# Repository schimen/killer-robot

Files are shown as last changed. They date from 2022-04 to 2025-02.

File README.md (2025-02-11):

# Killer robot

This repository contains all code and circuit for the robot **Rupert**, competing in [RoboWars](https://omegav.no/robotkrig) at [Omega Verksted](https://omegav.no/).

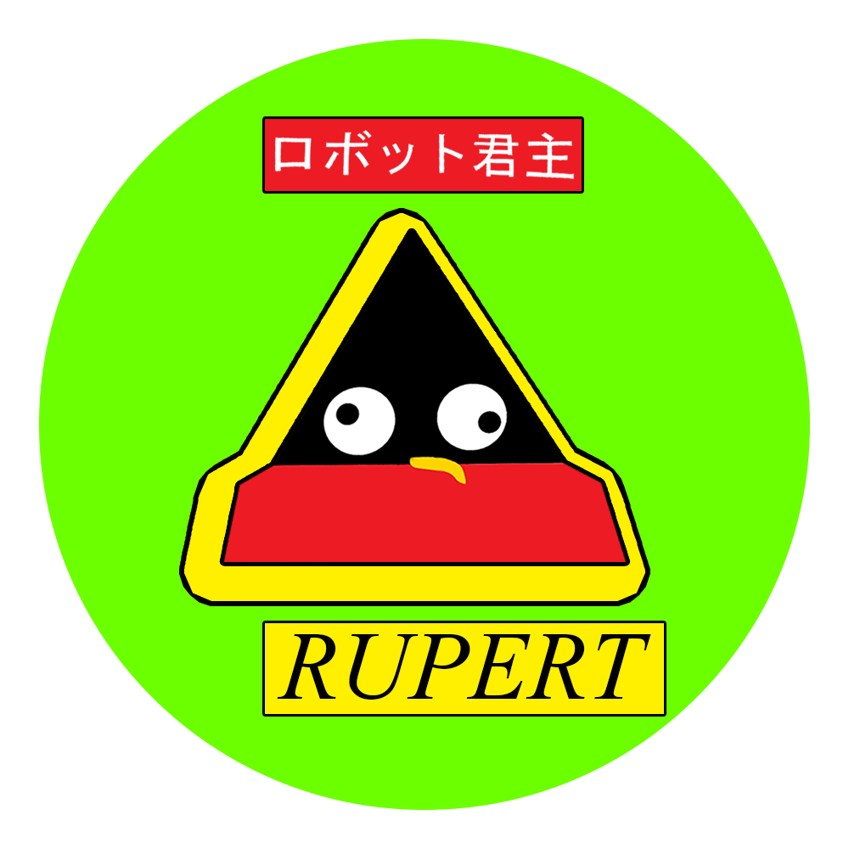
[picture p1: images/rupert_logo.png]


More information about Rupert and his history can be found in [history.md](./history.md).

## Projects

This repository consists of differenct projects that have different tasks in controlling the robot.
The different projects are:
- [Robot brain](./firmware/rupert-brain/): Firmware running on Rupert, receives commands and controls motors.
- [Robot pcb](./robot-pcb/): Printed circuit board supposed to control the robot. The robot brain runs on this hardware.
- [Robot control center](./control-center/): Python GUI program that controls the robot via commands.
- [Transmitter](./firmware/transmitter): Firmware for command transmitter, communicating with the control center via USB and the robot via radio.
This transmitter is deprecated, all communication with Rupert uses BLE via the "Robot control center".

## Zephyr guide

The firmware for Rupert is mainly developed in [Zephyr RTOS](https://www.zephyrproject.org/) and the SDK for Zephyr must be installed to build and upload firmware to the robot and the transmitter.
Zephyr is well documented and the latest documentation can be found [here](https://docs.zephyrproject.org/latest/index.html).

To install and get started with Zephyr, please follow [this guide](https://docs.zephyrproject.org/latest/develop/getting_started/index.html).
To install Zephyr in this project, make sure west and other dependencies from the guide is installed, and run `west update` from this repositories root folder. This will download Zephyr and relevant modules.
After installing and becoming familiar with the framework, you can install dependencies used by our hardware:
- Install ESP32 dependencies with `west espressif install`. Alternatively, follow [this guide](https://www.zephyrproject.org/zephyr-rtos-on-esp32/).

The Rupert firmware can now for example be built by the command `west build -b rupert_pcb firmware/rupert-brain` and then flashed with the command `west flash`.

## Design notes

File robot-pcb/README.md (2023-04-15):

# Robot PCB

This is the PCB that controls Rupert.
It consists of a ESP32 microcontroller that communicates over bluetooth.
Motors are controlled via motor-driver and via pwm outputs.

Schematic:

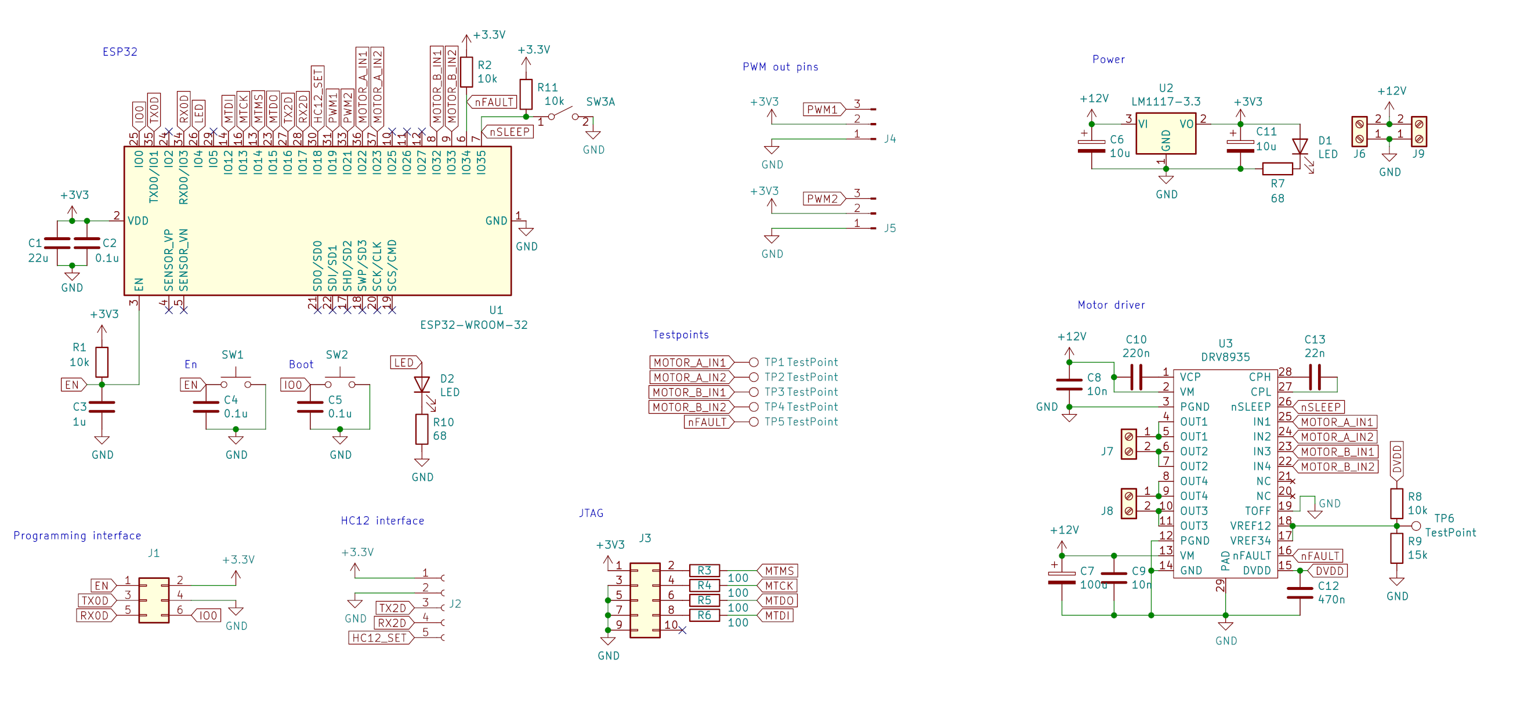
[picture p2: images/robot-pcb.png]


PCB 3d render:

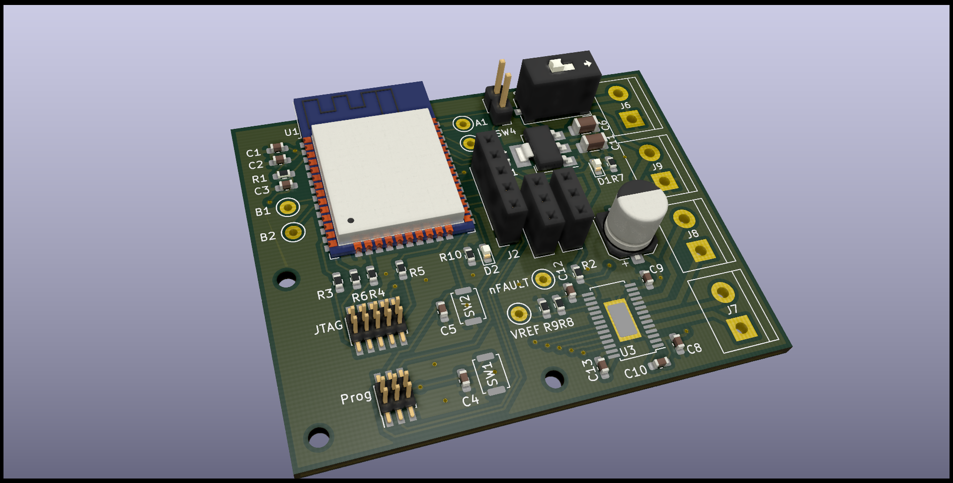
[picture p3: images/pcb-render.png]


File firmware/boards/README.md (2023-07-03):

# Rupert PCB zephyr configuration

This folder contains configuration describing the hardware running on Rupert. It describes the PCB and the expected connections to it. This board should be used when building and flashing code to Rupert.

An ESP32 microcontroller is the brain of the Rupert PCB and this folder therefore mostly uses the default ESP32 configuration for Zephyr.

See [the robot pcb folder](../../robot-pcb/) for details about the pcb.

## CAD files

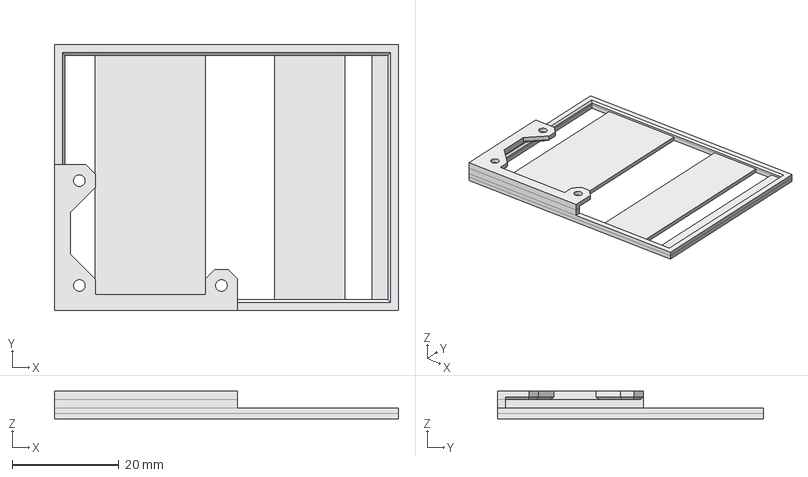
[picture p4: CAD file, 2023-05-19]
3d models/pcb-holder/robot_pcb_holder.FCStd
64.6 x 49.9 x 5.20 mm

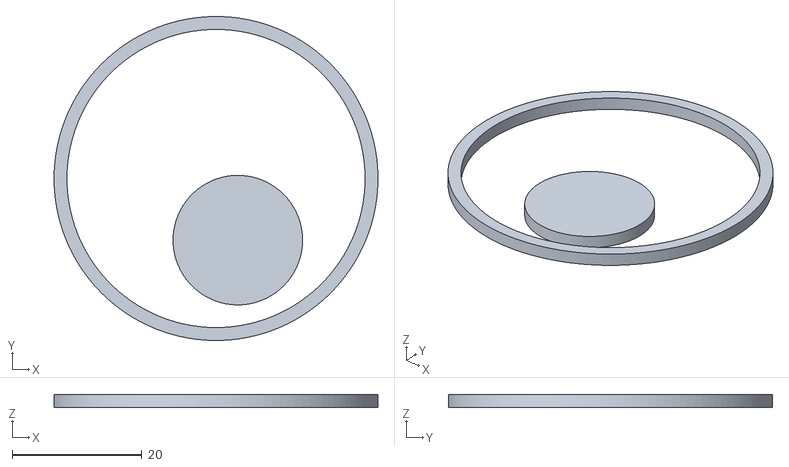
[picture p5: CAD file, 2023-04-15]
3d models/rupert-eyes/eye_black.stl
50.0 x 50.0 x 2.00

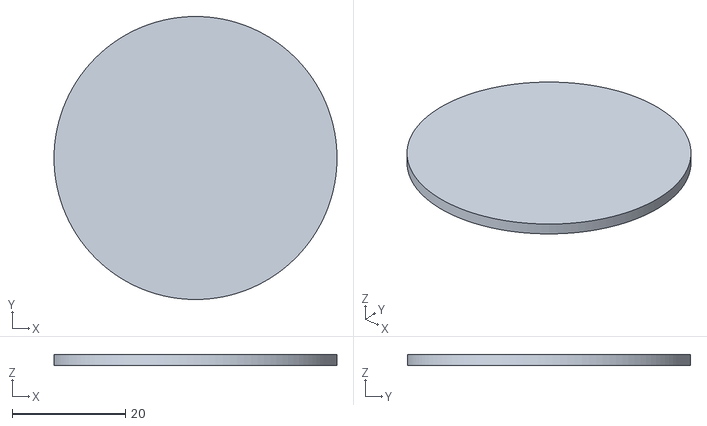
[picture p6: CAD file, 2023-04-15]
3d models/rupert-eyes/eye_hvite.stl
50.0 x 50.0 x 2.00

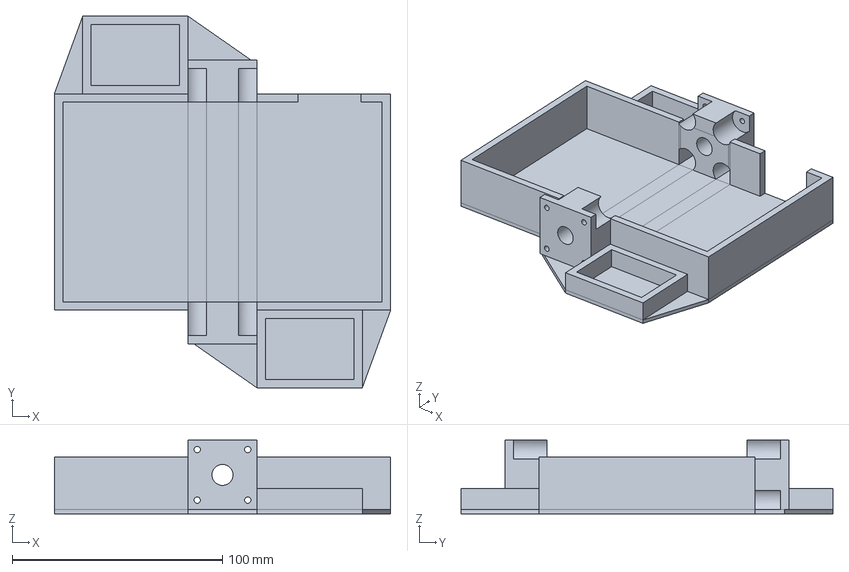
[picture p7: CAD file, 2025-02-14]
3d models/spinner-model/chassis-v3.FCStd
160.0 x 177.0 x 35.0 mm

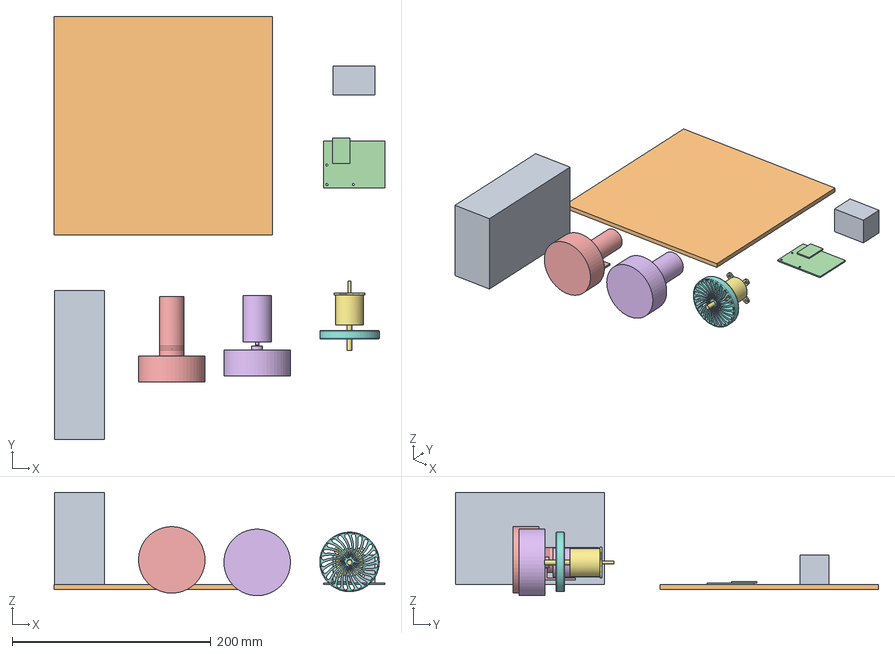
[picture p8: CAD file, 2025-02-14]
3d models/spinner-model/common-components.FCStd
333.1 x 426.0 x 104.0 mm
Battery V1
plate
PCB plate
ESP32 module
DC Motor 1
BL Motor car 1
BL Motor drone 1
Drone wheel 1

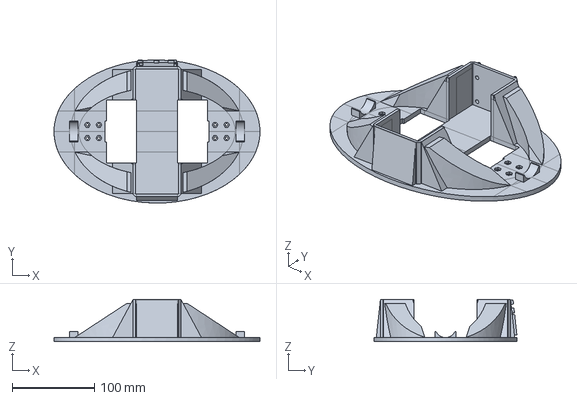
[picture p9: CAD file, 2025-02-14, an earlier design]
3d models/spinner-model/chassis-v1.FCStd
250.0 x 173.7 x 51.5 mm

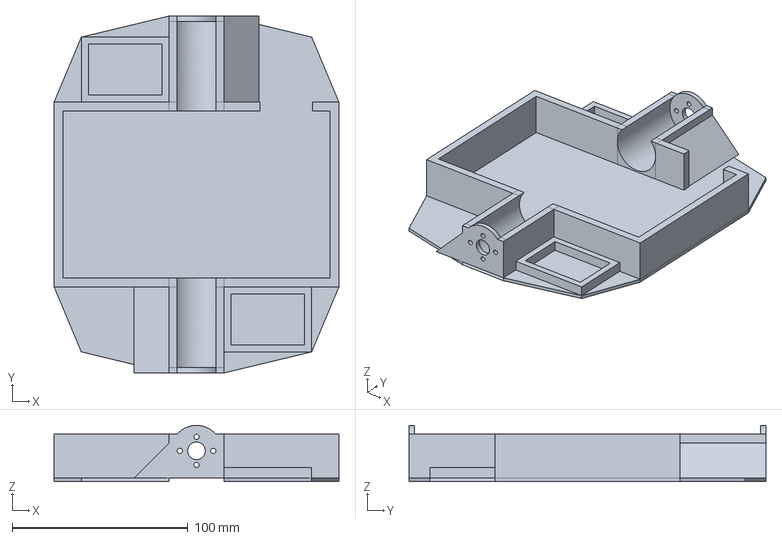
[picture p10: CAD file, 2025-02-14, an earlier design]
3d models/spinner-model/chassis-v2.FCStd
162.0 x 203.0 x 32.0 mm

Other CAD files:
3d models/pcb-holder/robot_pcb_holder.stl

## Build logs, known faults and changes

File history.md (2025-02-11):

# Rupert history

Rupert regularly undergoes changes, and so far there have been three versions of Rupert. The first Rupert competing in Robowars autumn 2021, Señor Rupert jr and Captain Rupert competing in robowars autumn 2022 and spring 2023 and our newest Rupert in autumn 2023.

Results can be seen at [confluence](https://confluence.omegav.no/display/OV/Tidligere+resultater).

### Rupert

*Autumn 2021* - ([Branch](https://github.com/schimen/killer-robot/tree/rupert-h2021))

The first Rupert to compete. Rupert did not have any efficient weapons, but he had a very durable shell which protected him from dangerous attacks. 
Rupert fought well but with a lack of attack he could not compete with the top. Rupert came in 3rd place.

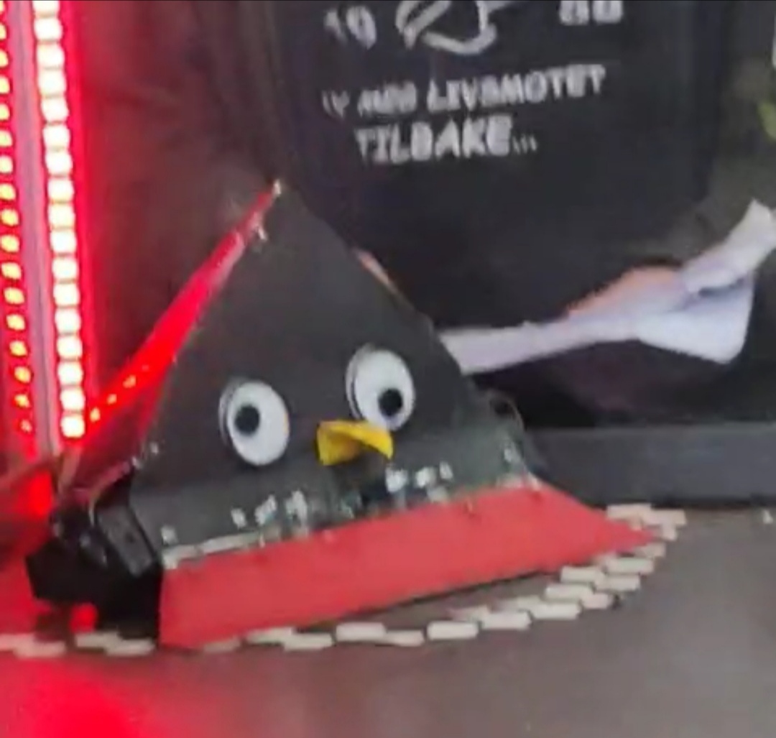
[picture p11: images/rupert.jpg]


### Señor Rupert jr

*Autumn 2022* - ([Branch](https://github.com/schimen/killer-robot/tree/rupert-h2022))

The next Rupert to compete had a 600g steel cylinder with teeth which was spinning at an impressive speed. Now that Rupert was equipped with a weapon, he was able to bite back at the opponents.
Rupert fought more aggressively this time and he did very well, but the electronics could not handle the heat and ended up burning themselves up in the process. Rupert came in 2nd place.

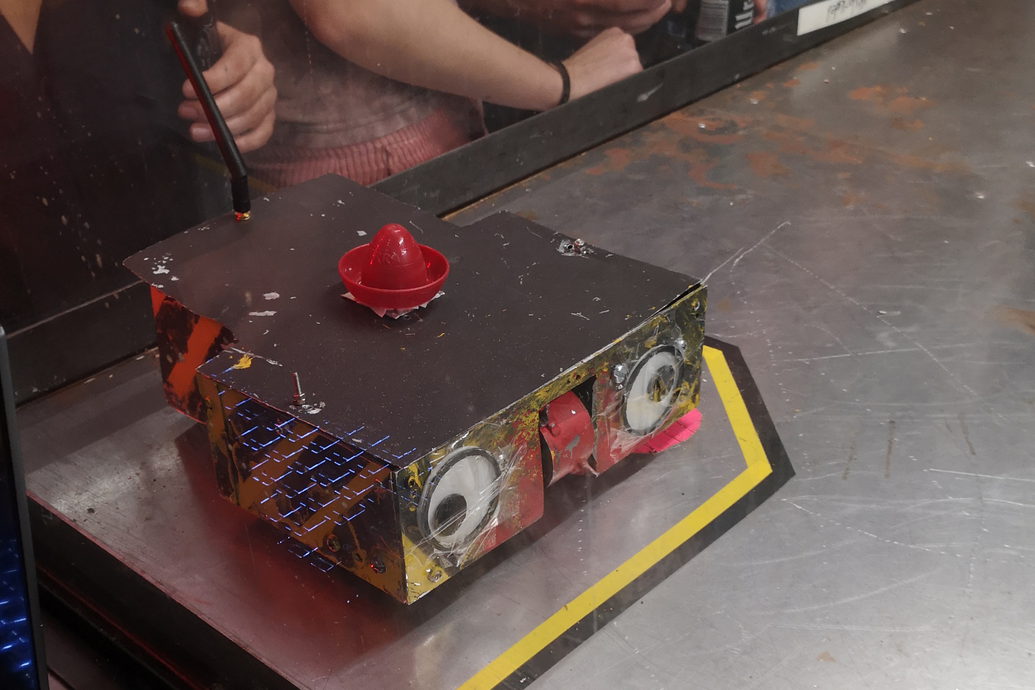
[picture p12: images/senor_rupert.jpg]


### Captain Rupert

*Spring 2023* - ([Branch](https://github.com/schimen/killer-robot/tree/rupert-v2023))

Rupert was again equipped with the teeth, and armed with more experience.
He fought like a pirate, with everything he got, but in the final fight his weapon was destroyed and the final battle was lost. He still came in a shared 1st place.

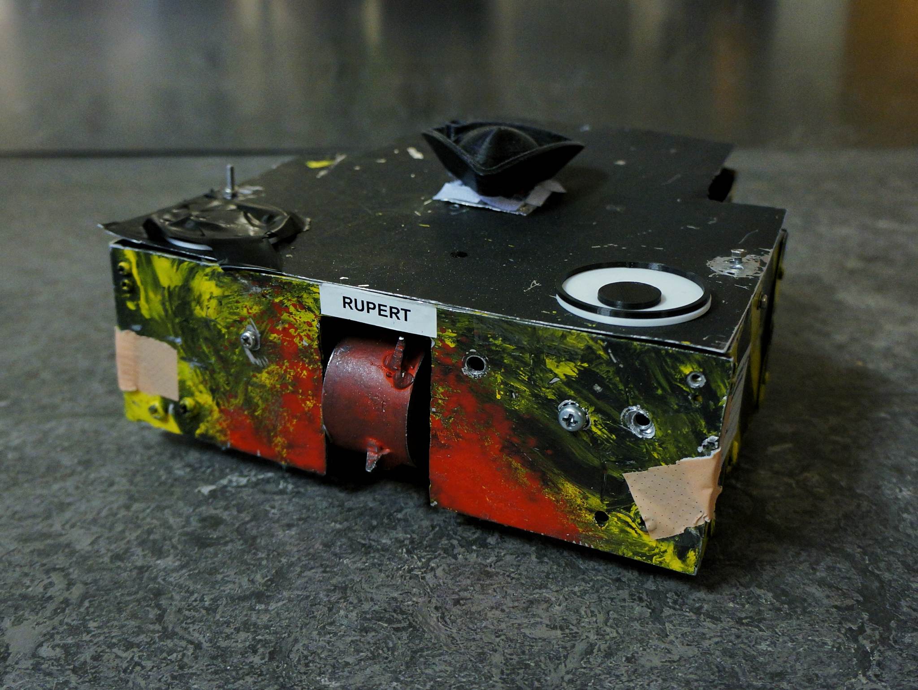
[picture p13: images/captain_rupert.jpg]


### Rupert

*Autumn 2023* - ([Branch](https://github.com/schimen/killer-robot/tree/rupert-h2023))

This time Rupert came out of his shell with a new strategy. He brought his padlock and threw it around at the opponents.
Rupert survived surprisingly long in the arena but was sadly obliterated immediately when he met an opponent with a fast spinning weapon. Rupert came in 3rd place.

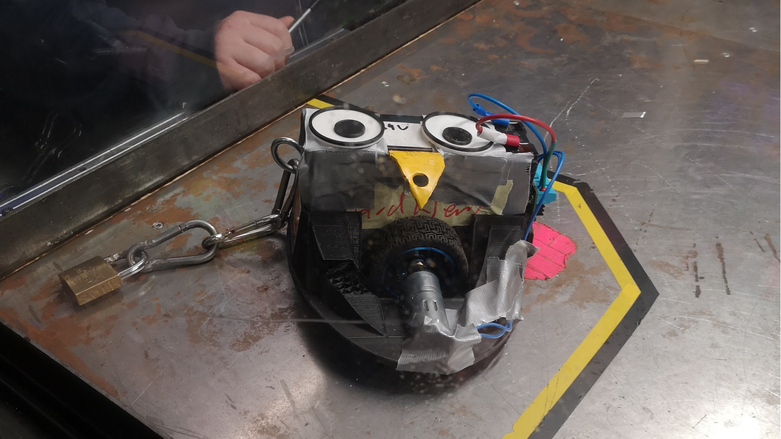
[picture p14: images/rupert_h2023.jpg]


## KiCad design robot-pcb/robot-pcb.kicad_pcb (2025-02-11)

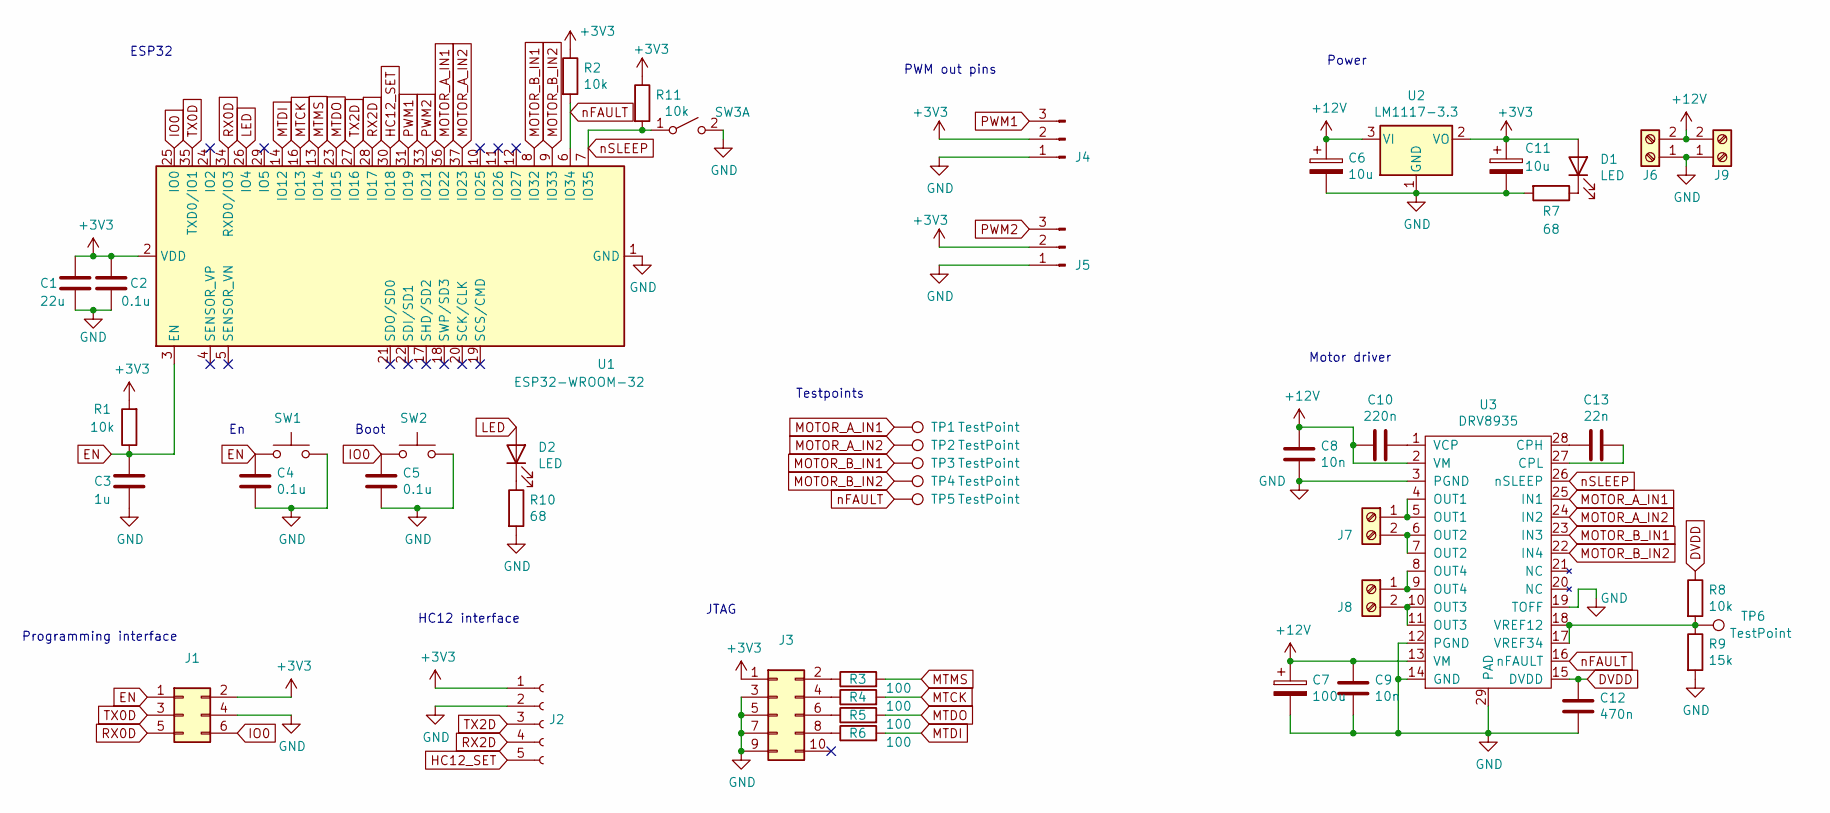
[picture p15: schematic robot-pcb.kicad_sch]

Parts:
C1: 22u; C_0603_1608Metric_Pad1.08x0.95mm_HandSolder
C2, C4, C5: 0.1u; C_0603_1608Metric_Pad1.08x0.95mm_HandSolder
C3: 1u; C_0603_1608Metric_Pad1.08x0.95mm_HandSolder
C6, C11: 10u; C_1206_3216Metric_Pad1.33x1.80mm_HandSolder
C7: 100u; CP_Elec_6.3x7.7
C8, C9: 10n; C_0603_1608Metric_Pad1.08x0.95mm_HandSolder
C10: 220n; C_0603_1608Metric_Pad1.08x0.95mm_HandSolder
C12: 470n; C_0603_1608Metric_Pad1.08x0.95mm_HandSolder
C13: 22n; C_0603_1608Metric_Pad1.08x0.95mm_HandSolder
D1, D2: LED; LED_0603_1608Metric_Pad1.05x0.95mm_HandSolder
J1: Conn_02x03_Odd_Even; PinHeader_2x03_P1.27mm_Vertical_SMD
J2: Conn_01x05_Female; PinSocket_1x05_P2.54mm_Vertical
J3: Conn_02x05_Odd_Even; PinHeader_2x05_P1.27mm_Vertical_SMD
J4, J5: Conn_01x03_Male; PinSocket_1x03_P2.54mm_Vertical
J6, J7, J8, J9: Screw_Terminal_01x02; TerminalBlock_bornier-2_P5.08mm
R1, R2, R8, R11: 10k; R_0603_1608Metric_Pad0.98x0.95mm_HandSolder
R3, R4, R5, R6: 100; R_0603_1608Metric_Pad0.98x0.95mm_HandSolder
R7, R10: 68; R_0603_1608Metric_Pad0.98x0.95mm_HandSolder
R9: 15k; R_0603_1608Metric_Pad0.98x0.95mm_HandSolder
SW1, SW2: SW_Push; wurth_tactile_sw
SW3: SW_DPST_x2; PinHeader_1x02_P2.54mm_Vertical
TP1, TP2, TP3, TP4, TP5, TP6: TestPoint; TestPoint_Keystone_5000-5004_Miniature
U1: ESP32-WROOM-32
U2: LM1117-3.3; SOT-223
U3: DRV8935; HTSSOP-28-1EP_4.4x9.7mm_P0.65mm_EP2.85x5.4mm

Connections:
+3V3: C1.1, C2.1, C11.1, D1.2 (A), J1.2, J2.1, J3.1, J4.2, J5.2, R1.2, R2.1, R11.1, U1.2 (VDD), U2.2 (VO), U2.4
+12V: C6.1, C7.1, C8.1, C9.1, C10.2, J6.2, J9.2, U2.3 (VI), U3.2 (VM), U3.13 (VM)
DVDD: C12.1, R8.1, U3.15 (DVDD)
EN: C3.1, C4.1, J1.1, R1.1, SW1.2, U1.3 (EN)
GND: C1.2, C2.2, C3.2, C4.2, C5.2, C6.2, C7.2, C8.2, C9.2, C11.2, C12.2, J1.4, J2.2, J3.3, J3.5, J3.7, J3.9, J4.1, J5.1, J6.1, J9.1, R7.2, R9.2, R10.2, SW1.1, SW2.2, SW3.2 (B), U1.1 (GND), U1.15 (GND), U1.38 (GND), U1.39 (GND), U2.1 (GND), U3.3 (PGND), U3.12 (PGND), U3.14 (GND), U3.19 (TOFF), U3.29 (PAD)
HC12_SET: J2.5, U1.30 (IO18)
IO0: C5.1, J1.6, SW2.1, U1.25 (IO0)
LED: D2.2 (A), U1.26 (IO4)
MOTOR_A_IN1: TP1.1, U1.36 (IO22), U3.25 (IN1)
MOTOR_A_IN2: TP2.1, U1.37 (IO23), U3.24 (IN2)
MOTOR_B_IN1: TP3.1, U1.8 (IO32), U3.23 (IN3)
MOTOR_B_IN2: TP4.1, U1.9 (IO33), U3.22 (IN4)
MTCK: R4.2, U1.16 (IO13)
MTDI: R6.2, U1.14 (IO12)
MTDO: R5.2, U1.23 (IO15)
MTMS: R3.2, U1.13 (IO14)
unnamed: C10.1, U3.1 (VCP)
unnamed: C13.1, U3.27 (CPL)
unnamed: C13.2, U3.28 (CPH)
unnamed: D1.1 (K), R7.1
unnamed: D2.1 (K), R10.1
unnamed: J3.2, R3.1
unnamed: J3.4, R4.1
unnamed: J3.6, R5.1
unnamed: J3.8, R6.1
unnamed: J7.1, U3.4 (OUT1), U3.5 (OUT1)
unnamed: J7.2, U3.6 (OUT2), U3.7 (OUT2)
unnamed: J8.1, U3.8 (OUT4), U3.9 (OUT4)
unnamed: J8.2, U3.10 (OUT3), U3.11 (OUT3)
unnamed: R8.2, R9.1, TP6.1, U3.17 (VREF34), U3.18 (VREF12)
PWM1: J4.3, U1.31 (IO19)
PWM2: J5.3, U1.33 (IO21)
RX0D: J1.5, U1.34 (RXD0/IO3)
RX2D: J2.4, U1.28 (IO17)
TX0D: J1.3, U1.35 (TXD0/IO1)
TX2D: J2.3, U1.27 (IO16)
nFAULT: R2.2, TP5.1, U1.6 (IO34), U3.16 (nFAULT)
nSLEEP: R11.2, SW3.1 (A), U1.7 (IO35), U3.26 (nSLEEP)

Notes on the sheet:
PWM out pins
ESP32
Motor driver
JTAG
HC12 interface
Power
Testpoints
Boot
Programming interface

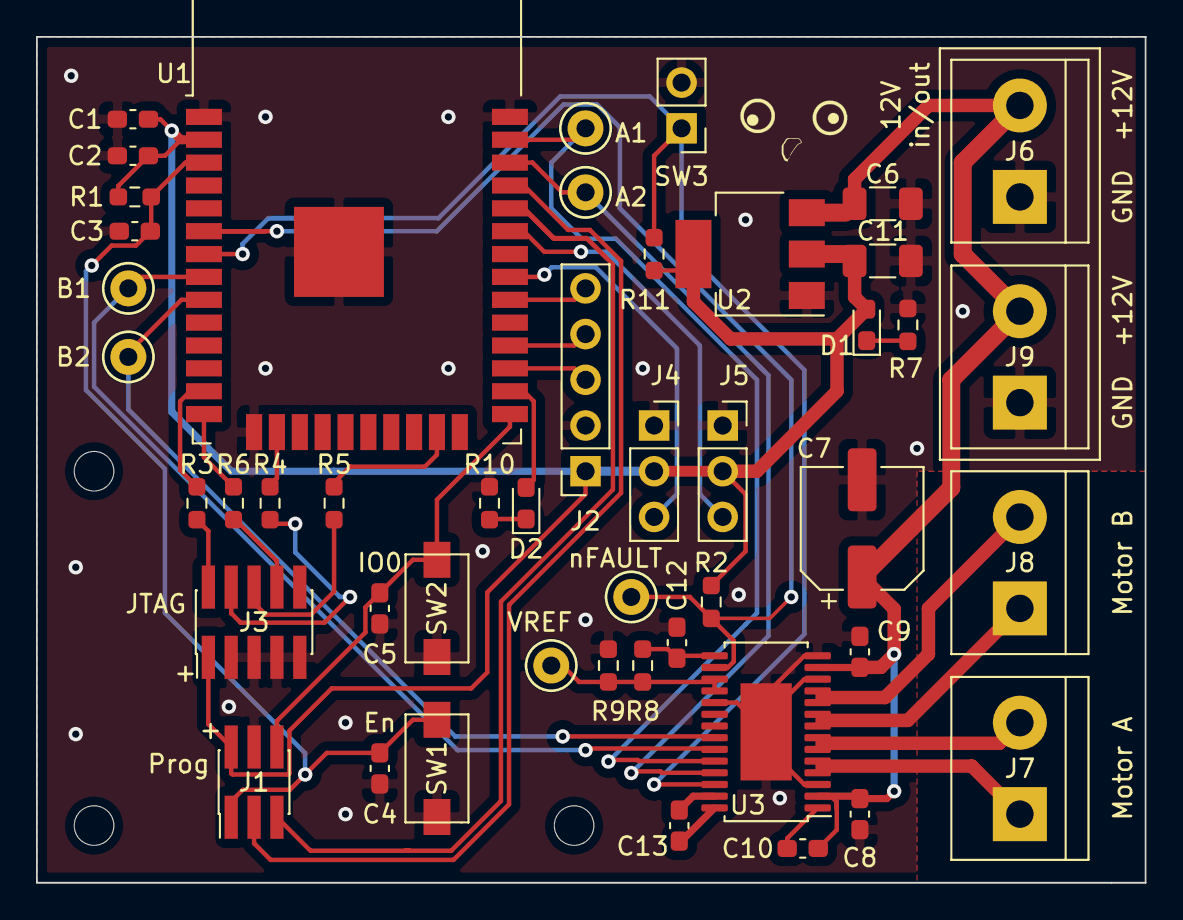
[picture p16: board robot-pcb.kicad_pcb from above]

Board: 2 copper layers, 61.6 x 47.0 mm, 47 parts (0 on the bottom side), 38 nets.

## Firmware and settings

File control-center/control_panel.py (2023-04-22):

"""
Control panel for killer robot
Made by Simen
"""
from os import system
from sys import platform
import threading
import tkinter as tk
from tkinter import ttk
import atexit
from time import sleep

from communication import \
    list_comports, Communication

# global sets for keeping an eye in the keys (little ugly solution, i know ;( )
pressed_keys = set()

# Global object for sending messages
comm = Communication()

class windows(tk.Tk):
    def __init__(self, *args, **kwargs):
        tk.Tk.__init__(self, *args, **kwargs)
        # Adding a title to the window
        self.wm_title("Control panel")
 
        # creating a frame and assigning it to container
        container = tk.Frame(self)
        # specifying the region where the frame is packed in root
        container.pack(side="top", fill="both", expand=True)
 
        # configuring the location of the container using grid
        container.grid_rowconfigure(0, weight=1)
        container.grid_columnconfigure(0, weight=1)

        self.frames = {}
        for i, F in enumerate((ControlOptions, Controls, DeviceOptions, BluetoothOptions)):
            frame = F(container, self)
            frame.grid(row=i, column=0)
            self.frames[frame.name] = frame

class Controls(tk.Frame):
    def __init__(self, parent, _):
        self.name = "Controls"
        tk.Frame.__init__(self, parent) 
        label = tk.Label(self, text="Controls")

        # Buttons that can be used controlling the robot.
        # These buttons does not do anything, but indicates which keys are pressed.
        Controls.buttons = dict()
        label.grid(row=0,column=1)
        control_buttons = { 'w': (1, 2)
                          , 'a': (2, 1)
                          , 's': (2, 2)
                          , 'd': (2, 3)
                          , 'shift': (3, 0)
                          , 'alt':   (3, 1)
                          , 'space': (3, 2)
                          }
        for key, (i, j) in control_buttons.items():
            new_button = tk.Button(
                self, 
                text = key,
            )
            new_button.grid(row=i, column=j)
            Controls.buttons[key] = new_button


class ControlOptions(tk.Frame):
    def __init__(self, parent, _):
        self.name = "ControlOptions"
        tk.Frame.__init__(self, parent) 
        label = tk.Label(self, text="Control Options")
        label.grid(row=0, column=1)

        # create entries for the options
        self.weapon_entry = create_option_entry(
            self, 'Weapon speed', (1, 0), self.weapon_speed
        )
        self.forward_entry = create_option_entry(
            self, 'Forward speed', (2, 0), self.forward_speed
        )
        self.backward_entry = create_option_entry(
            self, 'Backward speed', (3, 0), self.backward_speed
        )
        self.turnrate_entry = create_option_entry(
            self, 'Turning rate', (4, 0), self.turn_fraction
        )
        # setting alternate variables
        self.set_shift_values = create_option_check(
            self, (4, 0), 0, 
            text = 'Set shift values', onvalue = 1, offvalue = 0,
            command = self.set_shift_entries
        )
        # update the variables
        update_button = tk.Button(
            self, 
            text = 'Update values', command = self.update_values
        )
        update_button.grid(row=5, column=1)

    def update_values(self):
        # unfocus entries
        control_panel.focus()

        # set weapon speed
        weapon_var = get_speed(self.weapon_entry)
        if weapon_var is None:
            print('Weapon entry needs number')
            return

        # set forward speed
        forward_var = get_speed(self.forward_entry)
        if forward_var is None:
            print('Forward entry needs number')
            return
        
        # set bacwkard speed
        backward_var = get_speed(self.backward_entry)
        if backward_var is None:
            print('Backward entry needs number')
            return

        # set turning rate
        turnrate_str = self.turnrate_entry.get()
        # this will cause ValueError if `turnrate_str` can not be translated to a float
        try:
            min_turnrate = 0.1; max_turnrate = 2
            limited_value = limit_value(min_turnrate, max_turnrate, float(turnrate_str))
            turn_var = limited_value
        except ValueError:
            print('Turn fraction needs float')
            return

        if self.set_shift_values.get() > 0: # setting alternate speed
            print("Setting alternate speed")
            ControlOptions.weapon_speed_alt = weapon_var
            ControlOptions.forward_speed_alt = forward_var
            ControlOptions.backward_speed_alt = backward_var
            ControlOptions.turn_fraction_alt = turn_var
        else:                               # setting normal speed
            print("Setting normal speed")
            ControlOptions.weapon_speed = weapon_var
            ControlOptions.forward_speed = forward_var 
            ControlOptions.backward_speed = backward_var
            ControlOptions.turn_fraction = turn_var

    def set_shift_entries(self):
        # Clear all entries
        self.weapon_entry.delete(0, 4)
        self.forward_entry.delete(0, 4)
        self.backward_entry.delete(0, 4)
        self.turnrate_entry.delete(0, 4)

        if self.set_shift_values.get() > 0:
            self.weapon_entry.insert(0, str(ControlOptions.weapon_speed_alt))
            self.forward_entry.insert(0, str(ControlOptions.forward_speed_alt))
            self.backward_entry.insert(0, str(ControlOptions.backward_speed_alt))
            self.turnrate_entry.insert(0, str(ControlOptions.turn_fraction_alt))

        else:
            self.weapon_entry.insert(0, str(ControlOptions.weapon_speed))
            self.forward_entry.insert(0, str(ControlOptions.forward_speed))
            self.backward_entry.insert(0, str(ControlOptions.backward_speed))
            self.turnrate_entry.insert(0, str(ControlOptions.turn_fraction))

class DeviceOptions(tk.Frame):
    def __init__(self, parent, _):
        self.name = "DeviceOptions"
        tk.Frame.__init__(self, parent)
        label = tk.Label(self, text="Device Options")
        label.grid(row=0, column = 1)
        # Update the serial device list every 5 seconds
        threading.Thread(target=self.update_port_list, args=(5,), daemon=True).start()
        self.interface = comm.serial

        # Settings for transmitter device
        self.port_combo = create_option_combo(
            self, 'Port', (1, 0), []
        )
        self.baud_entry = create_option_entry(
            self, 'Baud rate', (2, 0), 115200)
        self.open_button = tk.Button(
            self, text = 'Open serial', command = self.open_serial
        )
        self.open_button.grid(row=3, column = 1)
        self.pings = []
        self.ping_var = tk.StringVar()
        tk.Label(
            self, textvariable=self.ping_var, 
        ).grid(row=3, column=0)

    def open_serial(self):
        # Close port if it is already open
        if self.interface.ser.is_open:
            comm.remove_interface(self.interface)
            self.interface.ser.close()
            print('Closed serial')
            self.ping_var.set('')
            self.open_button.config(text='Open serial')
            return
        
        # unfocus entries
        control_panel.focus()

        # Open serial
        baudrate = self.baud_entry.get()
        if not baudrate.isdigit():
            print('Baudrate must be an integer')
            return

        if self.interface.open_serial(
            self.port_combo.get(), int(baudrate)
            ):
            comm.add_interface(self.interface, 1, self.send_cb)
            # If the serial opened succesfully, 
            # the button will now close the serial
            self.open_button.config(text=f'Close serial')
            # print all serial communication to terminal
            threading.Thread(target=self.interface.read_serial_thread, daemon=True).start()

    def update_port_list(self, interval):
        while True:
            self.device_list = list_comports()
            self.port_combo['values'] = self.device_list
            sleep(interval)

    def send_cb(self, time):
        # Calculate ping based on last average 10 times
        self.pings.append(time)
        if len(self.pings) > 10:
            self.pings.pop(0)
        ping = sum(self.pings)/len(self.pings)
        # Set ping at control panel
        self.ping_var.set(f'Ping: {str(int(ping*1000)).rjust(3)} ms')

class BluetoothOptions(tk.Frame):
    def __init__(self, parent, _):
        self.name = "BluetoothOptions"
        tk.Frame.__init__(self, parent)
        label = tk.Label(self, text="Bluetooth options")
        label.grid(row=0, column = 1)
        self.pings = []
        self.interface = comm.bluetooth

        # Settings for ble device
        self.device_entry = create_option_entry(
            self, 'BLE device name', (1, 0), 'rupert'
        )
        self.open_button = tk.Button(
            self, text = 'Connect', command = self.bt_connect
        )
        self.open_button.grid(row=3, column = 1)
        self.ping_var = tk.StringVar()
        tk.Label(
            self, textvariable=self.ping_var, 
        ).grid(row=3, column=0)

    def bt_disconnect_cb(self, *_):
        comm.remove_interface(self.interface)
        self.ping_var.set('')
        print('Disconnected')
        try:
            self.open_button.config(text='Connect')
        except tk.TclError:
            print('GUI already closed')
            

    def bt_connect_cb(self):
        comm.add_interface(self.interface, 0, self.send_cb)
        self.open_button.config(text='Disconnect')
        print('Connected')

    def bt_connect(self):
        # Unfocus entries after pressing connect button
        control_panel.focus()

        # Disconnect if already connected
        if self.interface.client:
            if self.interface.client.is_connected:
                print('Try to disconnect')
                threading.Thread(
                    target=self.interface.disconnect,
                ).start()
                return

        name = self.device_entry.get()
        threading.Thread(
            target=self.interface.connect,
            args=(name, self.bt_connect_cb, self.bt_disconnect_cb),
            daemon=True

        ).start()
    
    def send_cb(self, time):
        # Calculate ping based on last average 10 times
        self.pings.append(time)
        if len(self.pings) > 10:
            self.pings.pop(0)
        ping = sum(self.pings)/len(self.pings)
        # Set ping at control panel
        self.ping_var.set(f'Ping: {str(int(ping*1000)).rjust(3)} ms')


# limit the values so they do not exceed max-values
def limit_value(minimum, maximum, value):
    if value <= minimum:
        return minimum   

    elif value >= maximum:
        return maximum

    return value

def get_speed(entry, min_val=-100, max_val=100):
    # set weapon speed
    entry_str = entry.get()
    if entry_str.isdigit():
        return limit_value(min_val, max_val, int(entry_str))
    else:
        return None

def key_press(event):
    """ called when key is pressed """
    pressed_keys.add(event.keycode)
    process_keys()

def key_release(event):
    """ called when key is released """
    pressed_keys.remove(event.keycode)
    process_keys()

def process_keys():
    """ called every time a key  is pressed or released """

    # different key numbers for different platforms (here is only linux and windows)
    if platform == 'linux':
        key_links = { 25: 'w'
                    , 38: 'a'
                    , 39: 's'
                    , 40: 'd'
                    ,  9: 'esc'
                    , 50: 'shift' 
                    , 65: 'space'
                    , 36: 'enter'
                    , 64: 'alt'
                    }
    else : 
        key_links = { 87: 'w'
                    , 65: 'a'
                    , 83: 's'
                    , 68: 'd'
                    , 27: 'esc'
                    , 16: 'shift' 
                    , 32: 'space'
                    , 36: 'enter' # windows value?
                    , 64: 'alt' # windows value?
                    }
    # if there is no change since last time keys were pressed
    if pressed_keys == process_keys.last_pressed_keys:
        return
    process_keys.last_pressed_keys = pressed_keys.copy()
    # filter out uninteresting keys
    relevant_keys = set(filter(lambda x: x in key_links, pressed_keys))
    # get key names from key numbers
    keys = list(map(lambda x: key_links[x], relevant_keys))
    # make buttons on control panel look like they are pressed
    ghostpress_buttons(keys)

    if 'esc' in keys: # unfocus stuff
        control_panel.focus()

    # Calculate motor speeds
    motor_a, motor_b, motor_w = calculate_speed(keys)
    
    # send the message :)
    comm.send_message(motor_a, motor_b, motor_w)

# Static variable for keeping tab on prevous pressed keys
process_keys.last_pressed_keys = set()

def ghostpress_buttons(keys):
    # make the keys look like they are pressed
    for key, button in Controls.buttons.items():
        if key in keys:
            button.config(relief='sunken') # pressed key
        else:
            button.config(relief='raised') # non pressed key

def calculate_speed(keys):
    if 'alt' in keys: # alternate speed
        weapon_speed   = ControlOptions.weapon_speed_alt
        forward_speed  = ControlOptions.forward_speed_alt
        backward_speed = ControlOptions.backward_speed_alt
        turn_fraction  = ControlOptions.turn_fraction_alt
    else:               # normal speed
        weapon_speed   = ControlOptions.weapon_speed
        forward_speed  = ControlOptions.forward_speed
        backward_speed = ControlOptions.backward_speed
        turn_fraction  = ControlOptions.turn_fraction

    motor_a = 0
    motor_b = 0
    motor_w = 0

    if 'w' in keys: # forward
        motor_a += forward_speed
        motor_b += forward_speed
    if 's' in keys: # backward
        motor_a -= backward_speed
        motor_b -= backward_speed
    if 'd' in keys: # right
        if motor_a != 0:
            motor_b -= int(turn_fraction*motor_a)
        else:
            motor_a += int(turn_fraction*forward_speed)
            motor_b -= int(turn_fraction*forward_speed)
    if 'a' in keys: # left
        if motor_a != 0:
                motor_a -= int(turn_fraction*motor_a)
        else: 
            motor_a -= int(turn_fraction*forward_speed)
            motor_b += int(turn_fraction*forward_speed)

    if 'space' in keys: # weapon on
        motor_w = weapon_speed

    if 'shift' in keys: # go reverse!
        # invert speed
        motor_w = -1*motor_w
        motor_a = -1*motor_a
        motor_b = -1*motor_b

    
    return limit_motor(motor_a+127), limit_motor(motor_b+127), limit_motor(motor_w+127)

def limit_motor(value):
    # limit the motor value
    if     value <=   0: return   0
    elif   value >= 255: return 255
    return value

def create_option_combo(root, label, pos, start_value):
    """
    Template for comboboxes
    """
    row, column = pos
    label = tk.Label(root, text=f'{label}:')
    label.grid(row=row, column=column)
    combo = ttk.Combobox(root, textvariable='Test')
    combo['values'] = start_value
    combo.grid(row=row, column=column+1)
    return combo

def create_option_entry(root, label, pos, start_value):
    """
    Template for option entries
    """
    row, column = pos
    label = tk.Label(root, text=f'{label}:')
    label.grid(row=row, column=column)
    entry = tk.Entry(root)
    entry.insert(0, str(start_value))
    entry.grid(row=row, column=column+1)
    return entry

def create_option_check(root, pos, start_value, **kwargs):
    """
    Template for checkbutton
    Add Checkbutton settings in keyword arguments (**kwargs)
    """
    checkbutton_variable = tk.IntVar()
    checkbutton_variable.set(start_value)
    transmitter_checkbutton = tk.Checkbutton(root, variable=checkbutton_variable, **kwargs)
    row, column = pos
    transmitter_checkbutton.grid(row=row,column=column)
    return checkbutton_variable

def xset_on():
    system('xset r on')

if __name__ == "__main__":
    # turn off key repeating, global os configuration (on linux)
    if platform == 'linux':
        # Turn xset off for linux machines, and turn it on again on exit
        system('xset r off')
        atexit.register(xset_on)


    # Variables for controlling the different speed values
    ControlOptions.weapon_speed = 20
    ControlOptions.forward_speed  = 100
    ControlOptions.backward_speed = 100
    ControlOptions.turn_fraction  = 1
    ControlOptions.weapon_speed_alt = 10
    ControlOptions.forward_speed_alt  = 75
    ControlOptions.backward_speed_alt = 75
    ControlOptions.turn_fraction_alt  = 0.5

    # tkinter setup
    control_panel = windows()
    control_panel.bind("<KeyPress>",   key_press)
    control_panel.bind("<KeyRelease>", key_release)
    # Run tkinter in a thread
    control_panel.mainloop()

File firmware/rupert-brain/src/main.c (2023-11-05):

#include <zephyr/device.h>
#include <zephyr/drivers/gpio.h>
#include <zephyr/drivers/pwm.h>
#include <zephyr/drivers/sensor.h>
#include <zephyr/drivers/spi.h>
#include <zephyr/logging/log.h>

#include "motor.h"
#include <command_lib/gatt_command.h>

// Register logger
LOG_MODULE_REGISTER(brain);

// GPIO structs
const struct gpio_dt_spec led0 = GPIO_DT_SPEC_GET(DT_ALIAS(led0), gpios);
const struct gpio_dt_spec nsleep = GPIO_DT_SPEC_GET(DT_ALIAS(nsleep), gpios);
struct gpio_callback sleep_callback;

// Sensor
const struct device *motion_sensor = DEVICE_DT_GET(DT_ALIAS(motion_sensor));

struct motor_control motor_a = {
    .en1 = PWM_DT_SPEC_GET(DT_ALIAS(a1)),
    .en2 = PWM_DT_SPEC_GET(DT_ALIAS(a2)),
};

struct motor_control motor_b = {
    .en1 = PWM_DT_SPEC_GET(DT_ALIAS(b1)),
    .en2 = PWM_DT_SPEC_GET(DT_ALIAS(b2)),
};

// Create workthread
K_THREAD_STACK_DEFINE(main_workthread_area, 512);
static struct k_work_q work_q;

/**
 * @brief Blink led0
 */
void blink() {
    gpio_pin_set_dt(&led0, 1);
    k_msleep(50);
    gpio_pin_set_dt(&led0, 0);
}

// Define blink worker
K_WORK_DEFINE(blink_worker, blink);

/**
 * @brief Blink led0 in workthread
 */
static inline void blink_wt() { k_work_submit(&blink_worker); }

/**
 * @brief Thread function that reads new messages and acts upon them
 *   This function is supposed to be used in a thread
 */
static void message_handler(void *p1, void *p2, void *p3) {
    ARG_UNUSED(p1);
    ARG_UNUSED(p2);
    ARG_UNUSED(p3);
    // Receive incoming commands
    struct command_data command;
    while (true) {
        if (get_command(&command) != 0) {
            // Did not receive command before timeout, turn motors off
            dc_motor_off(&motor_a);
            dc_motor_off(&motor_b);
            LOG_WRN("Command timed out, turn motor and weapon off");
            continue;
        }
        LOG_INF("New command %d (id %d) with value %d", command.key, command.id,
                command.value);
        blink_wt();
        switch (command.key) {
        case error_command: // an error ocurred!
            // acknowledge command, even though an error occurred
            set_ack(command.id);
            LOG_WRN("Warning: received error command (error %d)",
                    command.value);
            break;

        case ack_command: // set ack event when receiving ack
            set_ack(command.id);
            break;

        case ping_command: // ack ping command
            send_ack(command, 0);
            break;

        case left_motor_command:
            set_speed(&motor_a, command.value);
            send_ack(command, 0);
            break;

        case right_motor_command:
            set_speed(&motor_b, command.value);
            send_ack(command, 0);
            break;

        default: // unrecognized command, send error
            send_error(command, error_unrecognized);
            LOG_WRN("Warning: Unrecognized command");
            break;
        }
    }
}

// Define thread for handling incoming messages
#define MSGTHREAD_SIZE 1408
#define MSGTHREAD_PRI 4
K_THREAD_DEFINE(msg_handler_tid, MSGTHREAD_SIZE, message_handler, NULL, NULL,
                NULL, MSGTHREAD_PRI, 0, 0);

static void sleep_worker_func() {
    static int sleep_mode = 0;
    // 50ms debounce protection!
    k_msleep(50);
    // Read nsleep pin to see if device should sleep or wake up
    int state = gpio_pin_get_dt(&nsleep);
    if (state < 0) {
        LOG_ERR("Error %d: failed to read %s pin %d", state, nsleep.port->name,
                nsleep.pin);
    }
    // Return if sleep mode is equal to state
    if (sleep_mode == state) {
        return;
    }
    // Save state so it does not duplicate
    sleep_mode = state;
    if (sleep_mode) {
        // Stop communication
        k_thread_suspend(msg_handler_tid);
        // Turn off motors and weapon
        dc_motor_off(&motor_a);
        dc_motor_off(&motor_b);
        LOG_INF("Sleep mode on");
    } else {
        k_thread_resume(msg_handler_tid);
        LOG_INF("Sleep mode off");
    }
    blink();
}

// Define sleep worker
// (sleep and wake device in workthread, not interrupt)
K_WORK_DEFINE(sleep_worker, sleep_worker_func);

/**
 * @brief Callback for sleep-pin interrupt on sleep
 */
static void sleep_handler(const struct device *port, struct gpio_callback *cb,
                          uint32_t pins) {
    ARG_UNUSED(port);
    ARG_UNUSED(cb);
    ARG_UNUSED(pins);
    k_work_submit(&sleep_worker);
}

void main(void) {
    // Save error codes during initialization
    int err;

    // Init and start workqueue
    k_work_queue_init(&work_q);
    k_work_queue_start(&work_q, main_workthread_area,
                       K_THREAD_STACK_SIZEOF(main_workthread_area), 5, NULL);

    // Init motor control
    dc_motor_init(&motor_a, 0);
    dc_motor_init(&motor_b, 1);

    // Start bluetooth service
    peripheral_enable();

    // Configure nsleep pin and add sleep callback to it
    err = gpio_pin_configure_dt(&nsleep, GPIO_INPUT);
    if (err) {
        LOG_ERR("Error %d: failed to configure %s pin %d", err,
                nsleep.port->name, nsleep.pin);
    } else {
        // Check for sleep mode at initialization
        k_work_submit(&sleep_worker);
    }
    err = gpio_pin_interrupt_configure_dt(&nsleep, GPIO_INT_EDGE_BOTH);
    if (err) {
        LOG_ERR("Error %d: failed to configure interrupt on %s pin %d", err,
                nsleep.port->name, nsleep.pin);
    }
    gpio_init_callback(&sleep_callback, sleep_handler, BIT(nsleep.pin));
    err = gpio_add_callback(nsleep.port, &sleep_callback);
    if (err) {
        LOG_ERR("Error %d: failed to add callback to %s", err,
                nsleep.port->name);
    }

    // Init led0
    err = gpio_pin_configure_dt(&led0, GPIO_OUTPUT_INACTIVE);
    if (err) {
        LOG_ERR("Error %d: failed to configure %s pin %d", err, led0.port->name,
                led0.pin);
    }

    // Blink led when ready
    blink_wt();
    LOG_INF("Setup finished");
}

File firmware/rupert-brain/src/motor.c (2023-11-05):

#include "motor.h"

// Use logger from main.c
LOG_MODULE_DECLARE(brain);

// How much the speed will chenge each interval
#define DC_MOTOR_SPEED_STEP 10
#define BL_MOTOR_SPEED_STEP 2

// Length of delay between each change of speed
#define DC_MOTOR_SPEED_INTERVAL K_MSEC(40)
#define BL_MOTOR_SPEED_INTERVAL K_MSEC(20)

// Create threads for gradually controlling motor speed
#define STACK_SIZE 512
#define THREAD_PRIORITY 5
#define NUM_THREADS 2
// Structs for motor control threads
static struct k_thread motor_threads[NUM_THREADS];
// Define stack area for motor threads
K_THREAD_STACK_ARRAY_DEFINE(stacks, NUM_THREADS, STACK_SIZE);

// Define brushless and dc motor pwm periods
static const uint32_t DC_MOTOR_PERIOD = PWM_MSEC(1U);
static const uint32_t BL_MOTOR_PERIOD = PWM_MSEC(20U);
static const uint32_t BL_MOTOR_PULSE_MID = PWM_USEC(1500);
static const uint32_t BL_MOTOR_PULSE_RANGE = PWM_USEC(500U);
static const uint32_t BL_MOTOR_PULSE_MIN =
    BL_MOTOR_PULSE_MID - BL_MOTOR_PULSE_RANGE;
static const uint32_t BL_MOTOR_PULSE_MAX =
    BL_MOTOR_PULSE_MID + BL_MOTOR_PULSE_RANGE;

void dc_motor_init(struct motor_control *motor, int motor_index) {
    if (motor_index > NUM_THREADS - 1) {
        LOG_ERR(
            "Could not initialize motor with index %d. Can only have %d motors",
            motor_index, NUM_THREADS);
        return;
    }
    motor->speed = 127;
    motor->set_speed_func = &set_dc_motor_speed;
    motor->speed_step = DC_MOTOR_SPEED_STEP;
    motor->interval = DC_MOTOR_SPEED_INTERVAL;
    motor->thread =
        k_thread_create(&motor_threads[motor_index], stacks[motor_index],
                        STACK_SIZE, motor_speed_thread_callback, motor, NULL,
                        NULL, THREAD_PRIORITY, 0, K_NO_WAIT);
    set_dc_motor_speed(&motor->en1, &motor->en2, motor->speed);
}

void bl_motor_init(struct motor_control *motor, int motor_index) {
    if (motor_index > NUM_THREADS - 1) {
        LOG_ERR(
            "Could not initialize motor with index %d. Can only have %d motors",
            motor_index, NUM_THREADS);
        return;
    }
    motor->speed = 127;
    motor->set_speed_func = &set_bl_motor_speed;
    motor->speed_step = BL_MOTOR_SPEED_STEP;
    motor->interval = BL_MOTOR_SPEED_INTERVAL;
    motor->thread =
        k_thread_create(&motor_threads[motor_index], stacks[motor_index],
                        STACK_SIZE, motor_speed_thread_callback, motor, NULL,
                        NULL, THREAD_PRIORITY, 0, K_NO_WAIT);
    set_bl_motor_speed(&motor->en1, NULL, motor->speed);
}

void dc_motor_off(struct motor_control *motor) {
    pwm_set_dt(&motor->en1, DC_MOTOR_PERIOD, 0);
    pwm_set_dt(&motor->en2, DC_MOTOR_PERIOD, 0);
    motor->speed = 127;
}

void bl_motor_off(struct motor_control *motor) {
    pwm_set_dt(&motor->en1, BL_MOTOR_PERIOD, BL_MOTOR_PULSE_MID);
    motor->speed = 127;
}

void set_speed(struct motor_control *motor, uint8_t speed_u) {
    motor->speed = speed_u;
    k_thread_resume(motor->thread);
}

int32_t convert_speed(uint8_t speed_u) {
    int32_t speed = speed_u - 127;
    if (speed > 100) {
        speed = 100;
    } else if (speed < -100) {
        speed = -100;
    }
    return speed;
}

int set_dc_motor_speed(const struct pwm_dt_spec *en1,
                       const struct pwm_dt_spec *en2, uint8_t speed_u) {
    int32_t speed = convert_speed(speed_u);
    uint32_t pulse;
    int err1, err2;
    if (speed == 0) {
        err1 = pwm_set_dt(en1, DC_MOTOR_PERIOD, 0);
        err2 = pwm_set_dt(en2, DC_MOTOR_PERIOD, 0);
    } else if (speed > 0) {
        pulse = speed * ((DC_MOTOR_PERIOD - 1) / 100);
        if (pulse > DC_MOTOR_PERIOD) {
            pulse = DC_MOTOR_PERIOD;
        }
        err1 = pwm_set_dt(en1, DC_MOTOR_PERIOD, pulse);
        err2 = pwm_set_dt(en2, DC_MOTOR_PERIOD, 0);
    } else {
        speed = -1 * speed;
        pulse = speed * ((DC_MOTOR_PERIOD - 1) / 100);
        if (pulse > DC_MOTOR_PERIOD) {
            pulse = DC_MOTOR_PERIOD;
        }
        err1 = pwm_set_dt(en1, DC_MOTOR_PERIOD, 0);
        err2 = pwm_set_dt(en2, DC_MOTOR_PERIOD, pulse);
    }
    return err1 | err2;
}

int set_bl_motor_speed(const struct pwm_dt_spec *en1,
                       const struct pwm_dt_spec *en2, uint8_t speed_u) {
    ARG_UNUSED(en2);
    int32_t speed = convert_speed(speed_u);
    uint32_t pulse_offset = speed * (BL_MOTOR_PULSE_RANGE / 100);
    uint32_t pulse = BL_MOTOR_PULSE_MID + pulse_offset;
    if (pulse > BL_MOTOR_PULSE_MAX) {
        pulse = BL_MOTOR_PULSE_MAX;
    } else if (pulse < BL_MOTOR_PULSE_MIN) {
        pulse = BL_MOTOR_PULSE_MIN;
    }
    return pwm_set_dt(en1, BL_MOTOR_PERIOD, pulse);
}

void motor_speed_thread_callback(void *p1, void *p2, void *p3) {
    // Motor control struct
    struct motor_control *motor = p1;
    // Thread id of this thread
    k_tid_t thread_id = motor->thread;
    // Speed-step of this motor
    uint8_t step = motor->speed_step;
    // Timoeut of this function
    k_timeout_t interval = motor->interval;
    // Variable to keep desired speed, current speed and the difference
    uint8_t speed_u;
    uint8_t current_speed_u = 127;
    int16_t difference;
    // Callback function for setting the speed
    int (*set_speed_func)(const struct pwm_dt_spec *,
                          const struct pwm_dt_spec *, uint8_t) =
        motor->set_speed_func;

    while (true) {
        // Suspend before run
        if (motor->speed == current_speed_u) {
            k_thread_suspend(thread_id);
        }

        // Motor speed (unsigned)
        speed_u = motor->speed;

        if (speed_u < 27) {
            speed_u = 27;
        } else if (speed_u > 227) {
            speed_u = 227;
        }
        while (speed_u != current_speed_u) {
            speed_u = motor->speed;
            difference = speed_u - current_speed_u;
            if (difference > step) {
                difference = step;
            } else if (difference < -step) {
                difference = -step;
            }
            current_speed_u += difference;
            (*set_speed_func)(&motor->en1, &motor->en2, current_speed_u);
            k_sleep(interval);
        }
    }
}

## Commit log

2021-10-28 robot-brain: Motor control testing
2021-10-31 robot-control-panel: fixed entry focus issue and limited motor values
    [control_panel.py]
2021-11-03 robot-brain/Motor.h: "fixed" bug when nSteps is 0
2021-11-03 robot-brain: Added servo and got backup radio working
2021-11-04 Motor: now it makes sure the end speed matches the desired speed
2021-11-05 Control panel: added reverse mode
    [control_panel.py]
2021-11-05 control panel: fixed reverse function
    [control_panel.py]
2022-04-10 Remove arduino transmitter sketch
2022-04-10 Add transmitter circuit
    [transmitter-circuit.kicad_pcb, transmitter-circuit.sch]
2022-04-21 Update control panel to send motor commands correctly
    [control_panel.py]
2022-09-17 Add ble interface and rearrange interface drivers
2022-09-17 Add pcb for esp32
    [robot-pcb.kicad_pcb, robot-pcb.sch]
2022-09-19 Remove power switch from pcb
    [robot-pcb.kicad_pcb, robot-pcb.sch]
2022-09-26 Finish pcb v1.0
    [robot-pcb.kicad_pcb, robot-pcb.sch]
2022-09-26 Renamed drivers to command lib
2022-10-01 Add esp32 overlay
2022-10-01 Add pwm to config
2022-10-02 Add individual kconfig for gatt and uart
2022-10-02 Add esp32 to transmitter boards
2022-10-02 Fix bugs in esp32 overlay
2022-10-02 Move arduino backups
2022-10-03 Start testing with motors
2022-10-03 Fix notification print
2022-10-03 Fix pwm bug in motor lib
    [motor.c]
2022-10-11 Blink led in workthread
2022-10-11 Fix pwm issues in motor.c
    [motor.c]
2022-10-22 Update name bt device in robot brain
2022-10-24 Implement acceleration with threads for motors
2022-10-25 Check for too high pulse in pwm
    [motor.c]
2022-10-29 Add interrupt support for nsleep and add uart for commands
2022-10-29 Add uart commands in prj.conf
2022-10-29 Bad fix for pwm problem
    [motor.c]
2022-10-29 Adjust baudrate and print incoming commands in background
2022-10-30 Update robot-brain esp32 dts
2022-11-02 Small updates to pwm in overlay
2022-11-05 Update esp32 overlay
2022-11-05 Fix disconnected callback and print ping time bt
    [control_panel.py]
2022-11-06 Add motor and weapon off functions
2022-11-06 Move massage handler to thread and implement sleep mode
2022-11-08 Start with pwm chanel 0 and use 9600 for radio
2022-11-08 Add custom interval and step form motors
2022-11-08 Use new command start and end and init state pin high
2022-11-09 Fix port listing bug
    [control_panel.py]
2022-11-09 Init state pin logic low
2022-11-09 Turn off weapon pwm at 127
2022-11-09 Increase number of threads
2022-11-09 Fix update value function
    [control_panel.py]
2022-11-10 Major refactor for communication classes - Class for each interface - General interface sendcommand structure - Routinely ping all active interfaces and print result
2022-12-12 Bluetooth and control-panel fixes
    - Implement write-without response in gatt_command
    - Implement proper notifications
    - Use actual mtu in bleak
    - Other smaller fixes
    [control_panel.py]
2022-12-13 Use different pwm channels to fix buggy pwm
    [motor.c]
2023-04-15 Print RSSI when connecting to bt
2023-04-15 Remove Arduino backup
2023-04-15 Add some documentation for pcb
    [robot-pcb.kicad_sch, robot_pcb_holder.FCStd]
2023-04-15 Rename pcb-render image
2023-04-15 Resize images in pcb readme
2023-04-15 Add 3d models folder
    [eye_black.stl, eye_hvite.stl, robot_pcb_holder.FCStd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]
2023-04-22 Use reverse weapon again
    [control_panel.py]
2023-05-19 Update robot pcb holder and update kicad version
    [robot-pcb.kicad_pcb, robot_pcb_holder.FCStd]
2023-05-19 Add some print statements to scan program
2023-07-02 Add test drivers (not yet working)
2023-07-02 Rearrange firmware structure
    [transmitter-circuit.kicad_pcb, transmitter-circuit.sch]
2023-07-03 Apply refactor to driver code and make able to build
2023-07-03 Add spi library to header file
2023-07-03 Add alias and test code for motion-sensor
2023-07-03 Add rupert_pcb board
2023-07-03 Fix sensor driver log-level and device initialization
    [icm20948.c, main.c]
2023-08-24 Add non-working sensor implementation
2023-08-25 Refer to correct spi device and support float print
2023-08-27 Fix sensor reading bug and use max scale reading
    [icm20948.c, icm20948_spi.c]
2023-08-27 Add debug service for raw sensor values
2023-08-29 Add magnetometer
2023-08-30 Add some more delay for magnetometer
2023-08-30 Rewrite sensor test
2023-08-30 Use little endian for magnetometer
2023-08-30 Rewrite sensor data plotting program for reuse
2023-10-03 Add spinner test model
    [spinner-model.FCStd]
2023-10-10 Add spinner model v2
    [spinner-model.FCStd]
2023-10-14 Add timer to debug server notification
2023-10-17 Use new motor configuration and rework motor library for bl motor
    [main.c, motor.c]
2023-11-05 Go back to dc motors and remove motion sensor for robowars
2025-02-11 Update KiCad version
    [robot-pcb.kicad_pcb, robot-pcb.kicad_sch]
2025-02-11 Add chassis v3 model
    [spinner-model.FCStd]
2025-02-14 SPlit up spinner model to multiple projects
    [chassis-v1.FCStd, chassis-v2.FCStd, chassis-v3.FCStd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]
